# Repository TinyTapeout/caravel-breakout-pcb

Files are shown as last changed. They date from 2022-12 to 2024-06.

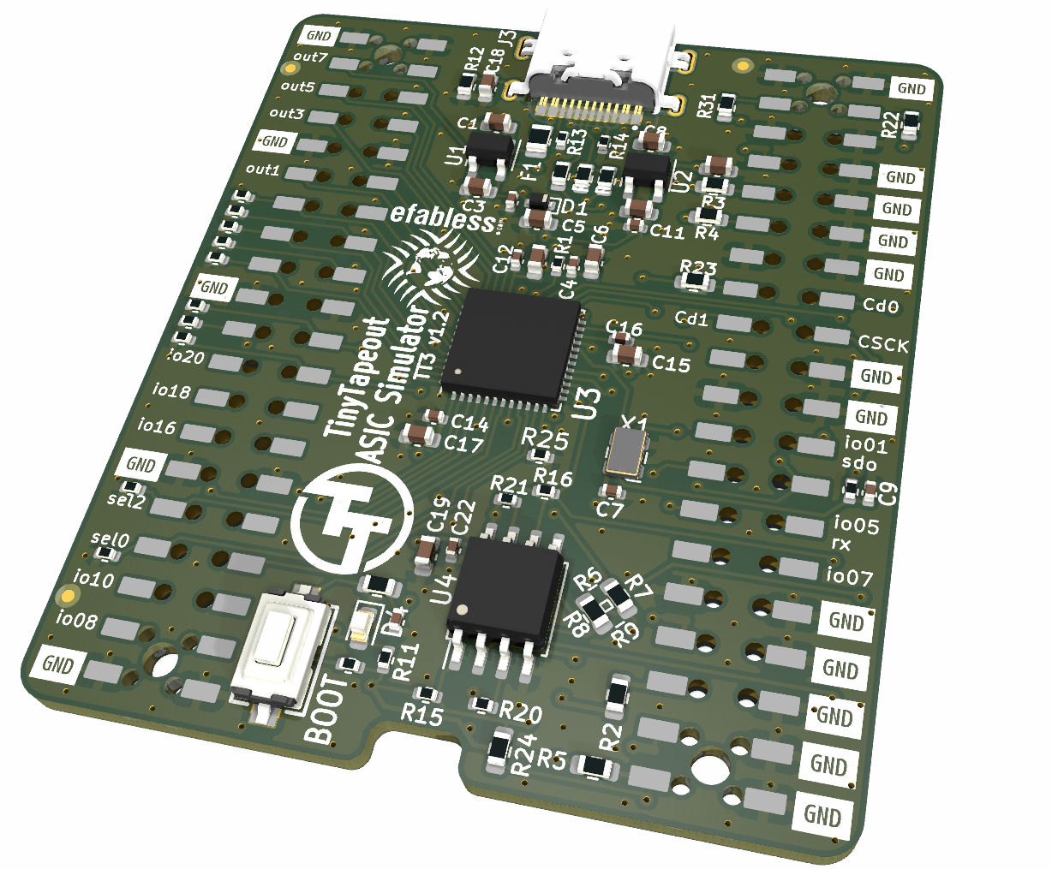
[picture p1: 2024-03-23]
ASIC-simulator/breakout-fpga-ICE40UP5K-TT3/doc/ice40up5kbkout-pcb.png

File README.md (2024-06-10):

# caravel-breakout-pcb - deprecated

> [!WARNING]
> This repo is deprecated. Use [TinyTapeout/breakout-pcb](https://github.com/tinytapeout/breakout-pcb) instead.

A set of breakouts/carrier boards for the Caravel ASIC used in eFabless MPW runs and a little FPGA adapter for simulating the TinyTapeout design, to be used alongside the [Tiny Tapeout 4+ Demo Board](https://github.com/TinyTapeout/tt-demo-pcb), the [Tiny Tapeout 1-3 Demo Board](https://github.com/TinyTapeout/tt123-demo-pcb), and/or other custom designs.

The ASIC board designs are based on the original breakout [published here](https://github.com/efabless/caravel_board/tree/main/hardware/breakout), optimised for single-sided surface mount assembly and ease of integration into other projects.

Design files are in KiCad 6 format, custom library parts can be found in [this external repo](https://github.com/omerk/ok-kicad-libs).

# PCBs sponsored by Aisler!

Thanks [Aisler](https://aisler.net/) for sponsoring our PCB development.

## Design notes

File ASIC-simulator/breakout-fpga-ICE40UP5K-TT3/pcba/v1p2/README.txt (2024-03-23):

TT3-compatible FPGA ASIC simulator 
(C) 2023,2024 Pat Deegan

This directory contains everything required for PCBA.

Gerbers in gerber/

B.O.M. to use in bom/BOM.csv

PnP placement file in placement/

Schematic and more info up one level, in doc/

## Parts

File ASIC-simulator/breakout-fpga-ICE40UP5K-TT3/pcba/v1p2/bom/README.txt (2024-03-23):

BOM stuffed depends on desired variant: see schematic.

However, for current PCBA we want to use something that can be used stand-alone, won't impact/require the demoboard flash (standalone variant).

Simplified and reviewed in 

   BOM.csv

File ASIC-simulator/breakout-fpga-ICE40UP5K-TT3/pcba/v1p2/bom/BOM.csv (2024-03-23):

Item | Qty | Reference | DNP | Value | Characteristics | MPN | MPN_ALT | DigikeyPN | Footprint | Datasheet | Display Value | Variant
Source: | caravel-breakout-fpga-ICE40UP5K-TT3.kicad_sch
Date: | Thu 11 Jan 2024 09:32:29 PM
Tool: | Eeschema 7.0.10-7.0.10~ubuntu22.04.1
Generator: | /usr/share/kicad/plugins/bom_csv_grouped_by_val_wDNP.py
Variants included: | {'PROG_CRAM': False, 'DEMOBOARD_DEPENDENT': False}
Component Count: | 72
Collated Components:
Item | Qty | Reference | DNP | Value | Characteristics | MPN | MPN_ALT | DigikeyPN | Footprint | Datasheet | Display Value
1 | 9 | C1,C3,C5,C6,C8,C10,C13,C15,C17 | 0 | 4.7u | 4.7u 0603 | CL10A475KP8NNNC | GRT188R61C475KE13J | 1276-1044-1-ND | Capacitor_SMD:C_0603_1608Metric
2 | 10 | C2,C4,C7,C9,C11,C12,C14,C16,C21,C22 | 0 | 0.1u | 0.1u 0402 | CL05A104KA5NNNC |  | 1276-1043-1-ND | Capacitor_SMD:C_0402_1005Metric
5 | 2 | CON1,CON2 | 0 | REF-182665-01 | 40 pos 100mil bottom + top | M20-7812045 | FH-00339 | 952-3218-ND | BreakoutCommon:FH-00339 | ~
6 | 1 | D1 | 0 | 1N4148WT-7 |  | 1N4148WT-7 | 1N4148XHE3-TP | 1N4148WTDICT-ND | Diode_SMD:D_SOD-523
8 | 1 | F1 | 0 | 350mA | Polyfuse 350mA Hold 0805 | 0ZCK0035FF2G |  | 507-1812-1-ND | Fuse:Fuse_0805_2012Metric | ~
9 | 1 | J3 | 0 | USB4500-03-0-A_REVA | USB 2 Recept 16+8 Dummy | USB4500-03-0-A |  | 2073-USB4500-03-0-ACT-ND | TinyTapeout:GCT_USB4500-03-0-A_REVA
10 | 1 | R1 | 0 | R_100R_0402 | 100R 1% 0402 | RC0402FR-07100RL |  | 311-100LRCT-ND | Resistor_SMD:R_0402_1005Metric | ~ | 100R
11 | 4 | R4,R5,R22,R24 | DNPs: 4 (final qty: 4) | 0R | 0R JUMPER 0603 | CRG0603ZR |  | A106051CT-ND | Resistor_SMD:R_0603_1608Metric | ~ | 0R
12 | 2 | R7,R8 | DNPs: 2 (final qty: 2) | 0R | 0R JUMPER 0603 | CRG0603ZR |  | A106051CT-ND | Resistor_SMD:R_0603_1608Metric |  | 0R
13 | 9 | R10,R15,R16,R20,R21,R25,R26,R28,R30 | 0 | R_10k_0402 | 10k 0402 | RC0402FR-0710KL |  | 311-10.0KLRCT-ND | Resistor_SMD:R_0402_1005Metric | ~ | 10k
16 | 2 | R13,R14 | 0 | 5.1k | 5.1k 0402 1% | AC0402FR-135K1L |  | 13-AC0402FR-135K1LCT-ND | Resistor_SMD:R_0402_1005Metric | ~
17 | 2 | R17,R29 | 0 | 1k5 | 1.5k 0603 1% | CR0603-FX-1501ELF | WR06X1501FTL | 118-CR0603-FX-1501ELFCT-ND | Resistor_SMD:R_0603_1608Metric | ~ | 1k5
18 | 2 | R18,R19 | 0 | 68R | 68R 0603 | CR0603-FX-68R0ELF | WR06X68R0FTL | CR0603-FX-68R0ELF | Resistor_SMD:R_0603_1608Metric | ~ | 68R
19 | 8 | R27,R32,R33,R34,R35,R36,R37,R38 | 0 | R_100k_0402 | 100k 0402 | RC0402FR-07100KL | WR04X1003FTL | 311-100KLRCT-ND | Resistor_SMD:R_0402_1005Metric | ~ | 100k
20 | 1 | SW1 | 0 | 434121025816 | NO MOM tactile switch | 434121025816 | TS10-63-26-BE-250-SMT-TR |  | TinyTapeout:434121025816 | ~
21 | 1 | U1 | 0 | AP2112K-3.3 |  | AP2112K-3.3TRG1 |  | AP2112K-3.3TRG1DICT-ND | Package_TO_SOT_SMD:SOT-23-5 | https://www.diodes.com/assets/Datasheets/AP2112.pdf
22 | 1 | U2 | 0 | AP2112K-1.2 |  | AP2112K-1.2TRG1 |  | 31-AP2112K-1.2TRG1CT-ND | Package_TO_SOT_SMD:SOT-23-5 | https://www.diodes.com/assets/Datasheets/AP2112.pdf
23 | 1 | U3 | 0 | ICE40UP5K-SG48ITR |  | ICE40UP5K-SG48I |  | 220-2212-1-ND | Package_DFN_QFN:QFN-48-1EP_7x7mm_P0.5mm_EP5.6x5.6mm
24 | 1 | U4 | 0 | W25Q32JVSSIM |  | W25Q32JVSSIQ |  | W25Q32JVSSIQ-ND | Package_SO:SOIC-8_5.23x5.23mm_P1.27mm
25 | 1 | X1 | 0 | 20MHz |  | 830208220401 |  | 1923-830208220401CT-ND | Oscillator:Oscillator_SMD_ECS_2520MV-xxx-xx-4Pin_2.5x2.0mm | https://www.ecsxtal.com/store/pdf/ECS-2520MV.pdf
Individual Components:
Item | Qty | Reference | DNP | Value | Characteristics | MPN | MPN_ALT | DigikeyPN | Footprint | Datasheet | Display Value | Variant
 |  | C1 |  | 4.7u | 4.7u 0603 | CL10A475KP8NNNC | GRT188R61C475KE13J | 1276-1044-1-ND | Capacitor_SMD:C_0603_1608Metric |  |  | USE_STANDALONE
 |  | C2 |  | 0.1u | 0.1u 0402 | CL05A104KA5NNNC |  | 1276-1043-1-ND | Capacitor_SMD:C_0402_1005Metric
 |  | C3 |  | 4.7u | 4.7u 0603 | CL10A475KP8NNNC | GRT188R61C475KE13J | 1276-1044-1-ND | Capacitor_SMD:C_0603_1608Metric |  |  | USE_STANDALONE
 |  | C4 |  | 0.1u | 0.1u 0402 | CL05A104KA5NNNC |  | 1276-1043-1-ND | Capacitor_SMD:C_0402_1005Metric
 |  | C5 |  | 4.7u | 4.7u 0603 | CL10A475KP8NNNC | GRT188R61C475KE13J | 1276-1044-1-ND | Capacitor_SMD:C_0603_1608Metric
 |  | C6 |  | 4.7u | 4.7u 0603 | CL10A475KP8NNNC | GRT188R61C475KE13J | 1276-1044-1-ND | Capacitor_SMD:C_0603_1608Metric
 |  | C7 |  | 0.1u | 0.1u 0402 | CL05A104KA5NNNC |  | 1276-1043-1-ND | Capacitor_SMD:C_0402_1005Metric
 |  | C8 |  | 4.7u | 4.7u 0603 | CL10A475KP8NNNC | GRT188R61C475KE13J | 1276-1044-1-ND | Capacitor_SMD:C_0603_1608Metric
 |  | C9 |  | 0.1u | 0.1u 0402 | CL05A104KA5NNNC |  | 1276-1043-1-ND | Capacitor_SMD:C_0402_1005Metric
 |  | C10 |  | 4.7u | 4.7u 0603 | CL10A475KP8NNNC | GRT188R61C475KE13J | 1276-1044-1-ND | Capacitor_SMD:C_0603_1608Metric
 |  | C11 |  | 0.1u | 0.1u 0402 | CL05A104KA5NNNC |  | 1276-1043-1-ND | Capacitor_SMD:C_0402_1005Metric
 |  | C12 |  | 0.1u | 0.1u 0402 | CL05A104KA5NNNC |  | 1276-1043-1-ND | Capacitor_SMD:C_0402_1005Metric
 |  | C13 |  | 4.7u | 4.7u 0603 | CL10A475KP8NNNC | GRT188R61C475KE13J | 1276-1044-1-ND | Capacitor_SMD:C_0603_1608Metric
 |  | C14 |  | 0.1u | 0.1u 0402 | CL05A104KA5NNNC |  | 1276-1043-1-ND | Capacitor_SMD:C_0402_1005Metric
 |  | C15 |  | 4.7u | 4.7u 0603 | CL10A475KP8NNNC | GRT188R61C475KE13J | 1276-1044-1-ND | Capacitor_SMD:C_0603_1608Metric
 |  | C16 |  | 0.1u | 0.1u 0402 | CL05A104KA5NNNC |  | 1276-1043-1-ND | Capacitor_SMD:C_0402_1005Metric
 |  | C17 |  | 4.7u | 4.7u 0603 | CL10A475KP8NNNC | GRT188R61C475KE13J | 1276-1044-1-ND | Capacitor_SMD:C_0603_1608Metric
 |  | C18 | DNP | 6800pF | 6800p 0603 |  |  |  | Capacitor_SMD:C_0603_1608Metric | ~ |  | USB
 |  | C19 | DNP | DNI |  |  |  |  | Capacitor_SMD:C_0603_1608Metric
 |  | C20 | DNP | DNI |  |  |  |  | Capacitor_SMD:C_0603_1608Metric
 |  | C21 |  | 0.1u | 0.1u 0402 | CL05A104KA5NNNC |  | 1276-1043-1-ND | Capacitor_SMD:C_0402_1005Metric
 |  | C22 |  | 0.1u | 0.1u 0402 | CL05A104KA5NNNC |  | 1276-1043-1-ND | Capacitor_SMD:C_0402_1005Metric
 |  | CON1 |  | REF-182665-01 | 40 pos 100mil bottom + top | M20-7812045 | FH-00339 | 952-3218-ND | BreakoutCommon:FH-00339 | ~
 |  | CON2 |  | REF-182665-01 | 40 pos 100mil bottom + top | M20-7812045 | FH-00339 | 952-3218-ND | BreakoutCommon:FH-00339 | ~
 |  | D1 |  | 1N4148WT-7 |  | 1N4148WT-7 | 1N4148XHE3-TP | 1N4148WTDICT-ND | Diode_SMD:D_SOD-523
 |  | D4 | DNP | LED |  |  |  |  | LED_SMD:LED_0603_1608Metric | ~
 |  | F1 |  | 350mA | Polyfuse 350mA Hold 0805 | 0ZCK0035FF2G |  | 507-1812-1-ND | Fuse:Fuse_0805_2012Metric | ~ |  | USB
 |  | J3 |  | USB4500-03-0-A_REVA | USB 2 Recept 16+8 Dummy | USB4500-03-0-A |  | 2073-USB4500-03-0-ACT-ND | TinyTapeout:GCT_USB4500-03-0-A_REVA
 |  | R1 |  | R_100R_0402 | 100R 1% 0402 | RC0402FR-07100RL |  | 311-100LRCT-ND | Resistor_SMD:R_0402_1005Metric | ~ | 100R
 |  | R2 | DNP | 0R | 0R JUMPER 0603 | CRG0603ZR |  | A106051CT-ND | Resistor_SMD:R_0603_1608Metric | ~ | 0R | DEMOBOARD_DEPENDENT
 |  | R3 | DNP | 0R | 0R JUMPER 0603 | CRG0603ZR |  | A106051CT-ND | Resistor_SMD:R_0603_1608Metric | ~ | 0R | DEMOBOARD_DEPENDENT
 |  | R4 |  | 0R | 0R JUMPER 0603 | CRG0603ZR |  | A106051CT-ND | Resistor_SMD:R_0603_1608Metric | ~ | 0R | DEMOBOARD_BACKPOWERED
 |  | R5 |  | 0R | 0R JUMPER 0603 | CRG0603ZR |  | A106051CT-ND | Resistor_SMD:R_0603_1608Metric | ~ | 0R | DEMOBOARD_BACKPOWERED
 |  | R6 | DNP | 0R | 0R JUMPER 0603 | CRG0603ZR |  | A106051CT-ND | Resistor_SMD:R_0603_1608Metric |  | 0R | PROG_CRAM
 |  | R7 |  | 0R | 0R JUMPER 0603 | CRG0603ZR |  | A106051CT-ND | Resistor_SMD:R_0603_1608Metric |  | 0R | PROG_FLASH
 |  | R8 |  | 0R | 0R JUMPER 0603 | CRG0603ZR |  | A106051CT-ND | Resistor_SMD:R_0603_1608Metric |  | 0R | PROG_FLASH
 |  | R9 | DNP | 0R | 0R JUMPER 0603 | CRG0603ZR |  | A106051CT-ND | Resistor_SMD:R_0603_1608Metric |  | 0R | PROG_CRAM
 |  | R10 |  | R_10k_0402 | 10k 0402 | RC0402FR-0710KL |  | 311-10.0KLRCT-ND | Resistor_SMD:R_0402_1005Metric | ~ | 10k
 |  | R11 | DNP | R_2k_0402 | 2k 0402 | RC0402FR-072KL |  | 311-2KLRCT-ND | Resistor_SMD:R_0402_1005Metric | ~ | 2k
 |  | R12 | DNP | 1M | 1M 0603 |  |  |  | Resistor_SMD:R_0603_1608Metric | ~ |  | USB
 |  | R13 |  | 5.1k | 5.1k 0402 1% | AC0402FR-135K1L |  | 13-AC0402FR-135K1LCT-ND | Resistor_SMD:R_0402_1005Metric | ~ |  | USB
 |  | R14 |  | 5.1k | 5.1k 0402 1% | AC0402FR-135K1L |  | 13-AC0402FR-135K1LCT-ND | Resistor_SMD:R_0402_1005Metric | ~ |  | USB
 |  | R15 |  | R_10k_0402 | 10k 0402 | RC0402FR-0710KL |  | 311-10.0KLRCT-ND | Resistor_SMD:R_0402_1005Metric | ~ | 10k
 |  | R16 |  | R_10k_0402 | 10k 0402 | RC0402FR-0710KL |  | 311-10.0KLRCT-ND | Resistor_SMD:R_0402_1005Metric | ~ | 10k
 |  | R17 |  | 1k5 | 1.5k 0603 1% | CR0603-FX-1501ELF | WR06X1501FTL | 118-CR0603-FX-1501ELFCT-ND | Resistor_SMD:R_0603_1608Metric | ~ | 1k5 | USB_COMM
 |  | R18 |  | 68R | 68R 0603 | CR0603-FX-68R0ELF | WR06X68R0FTL | CR0603-FX-68R0ELF | Resistor_SMD:R_0603_1608Metric | ~ | 68R | USB_COMM
 |  | R19 |  | 68R | 68R 0603 | CR0603-FX-68R0ELF | WR06X68R0FTL | CR0603-FX-68R0ELF | Resistor_SMD:R_0603_1608Metric | ~ | 68R | USB_COMM
 |  | R20 |  | R_10k_0402 | 10k 0402 | RC0402FR-0710KL |  | 311-10.0KLRCT-ND | Resistor_SMD:R_0402_1005Metric | ~ | 10k
 |  | R21 |  | R_10k_0402 | 10k 0402 | RC0402FR-0710KL |  | 311-10.0KLRCT-ND | Resistor_SMD:R_0402_1005Metric | ~ | 10k
 |  | R22 |  | 0R | 0R JUMPER 0603 | CRG0603ZR |  | A106051CT-ND | Resistor_SMD:R_0603_1608Metric | ~ | 0R
 |  | R23 | DNP | 0R | 0R JUMPER 0603 | CRG0603ZR |  | A106051CT-ND | Resistor_SMD:R_0603_1608Metric | ~ | 0R | DEMOBOARD_DEPENDENT
 |  | R24 |  | 0R | 0R JUMPER 0603 | CRG0603ZR |  | A106051CT-ND | Resistor_SMD:R_0603_1608Metric | ~ | 0R | USE_STANDALONE
 |  | R25 |  | R_10k_0402 | 10k 0402 | RC0402FR-0710KL |  | 311-10.0KLRCT-ND | Resistor_SMD:R_0402_1005Metric | ~ | 10k
 |  | R26 |  | R_10k_0402 | 10k 0402 | RC0402FR-0710KL |  | 311-10.0KLRCT-ND | Resistor_SMD:R_0402_1005Metric | ~ | 10k
 |  | R27 |  | R_100k_0402 | 100k 0402 | RC0402FR-07100KL | WR04X1003FTL | 311-100KLRCT-ND | Resistor_SMD:R_0402_1005Metric | ~ | 100k
 |  | R28 |  | R_10k_0402 | 10k 0402 | RC0402FR-0710KL |  | 311-10.0KLRCT-ND | Resistor_SMD:R_0402_1005Metric | ~ | 10k
 |  | R29 |  | 1k5 | 1.5k 0603 1% | CR0603-FX-1501ELF | WR06X1501FTL | 118-CR0603-FX-1501ELFCT-ND | Resistor_SMD:R_0603_1608Metric | ~ | 1k5
 |  | R30 |  | R_10k_0402 | 10k 0402 | RC0402FR-0710KL |  | 311-10.0KLRCT-ND | Resistor_SMD:R_0402_1005Metric | ~ | 10k
 |  | R31 | DNP | 0R | 0R JUMPER 0603 | CRG0603ZR |  | A106051CT-ND | Resistor_SMD:R_0603_1608Metric | ~ | 0R | DEMOBOARD_DEPENDENT
 |  | R32 |  | R_100k_0402 | 100k 0402 | RC0402FR-07100KL | WR04X1003FTL | 311-100KLRCT-ND | Resistor_SMD:R_0402_1005Metric | ~ | 100k
 |  | R33 |  | R_100k_0402 | 100k 0402 | RC0402FR-07100KL | WR04X1003FTL | 311-100KLRCT-ND | Resistor_SMD:R_0402_1005Metric | ~ | 100k
 |  | R34 |  | R_100k_0402 | 100k 0402 | RC0402FR-07100KL | WR04X1003FTL | 311-100KLRCT-ND | Resistor_SMD:R_0402_1005Metric | ~ | 100k
 |  | R35 |  | R_100k_0402 | 100k 0402 | RC0402FR-07100KL | WR04X1003FTL | 311-100KLRCT-ND | Resistor_SMD:R_0402_1005Metric | ~ | 100k
 |  | R36 |  | R_100k_0402 | 100k 0402 | RC0402FR-07100KL | WR04X1003FTL | 311-100KLRCT-ND | Resistor_SMD:R_0402_1005Metric | ~ | 100k
 |  | R37 |  | R_100k_0402 | 100k 0402 | RC0402FR-07100KL | WR04X1003FTL | 311-100KLRCT-ND | Resistor_SMD:R_0402_1005Metric | ~ | 100k
 |  | R38 |  | R_100k_0402 | 100k 0402 | RC0402FR-07100KL | WR04X1003FTL | 311-100KLRCT-ND | Resistor_SMD:R_0402_1005Metric | ~ | 100k
 |  | SW1 |  | 434121025816 | NO MOM tactile switch | 434121025816 | TS10-63-26-BE-250-SMT-TR |  | TinyTapeout:434121025816 | ~
 |  | U1 |  | AP2112K-3.3 |  | AP2112K-3.3TRG1 |  | AP2112K-3.3TRG1DICT-ND | Package_TO_SOT_SMD:SOT-23-5 | https://www.diodes.com/assets/Datasheets/AP2112.pdf |  | USE_STANDALONE
 |  | U2 |  | AP2112K-1.2 |  | AP2112K-1.2TRG1 |  | 31-AP2112K-1.2TRG1CT-ND | Package_TO_SOT_SMD:SOT-23-5 | https://www.diodes.com/assets/Datasheets/AP2112.pdf
 |  | U3 |  | ICE40UP5K-SG48ITR |  | ICE40UP5K-SG48I |  | 220-2212-1-ND | Package_DFN_QFN:QFN-48-1EP_7x7mm_P0.5mm_EP5.6x5.6mm
 |  | U4 |  | W25Q32JVSSIM |  | W25Q32JVSSIQ |  | W25Q32JVSSIQ-ND | Package_SO:SOIC-8_5.23x5.23mm_P1.27mm |  |  | USE_STANDALONE
 |  | X1 |  | 20MHz |  | 830208220401 |  | 1923-830208220401CT-ND | Oscillator:Oscillator_SMD_ECS_2520MV-xxx-xx-4Pin_2.5x2.0mm | https://www.ecsxtal.com/store/pdf/ECS-2520MV.pdf |  | USE_STANDALONE

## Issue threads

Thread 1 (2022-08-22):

add easily probable ground power pads

mattvenn, 2022-08-22:
or use something like microbit. could put these on the motherboard too / instead

omerk, 2023-01-01:
With long headers poking through the "pass through", connectors probing individual signals should be fairly easy already but I'll see if we can add an easy-to-clip-to-scope-ground exposed ground pad like the TI devboards:

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

And ditto: it might not be a bad idea to have some easy to poke/clip test points on the demo board too. I'll add an issue on that repo.

omerk, 2023-03-20:
Closing this as we've moved this on to the main board.

Closed 2023-03-20.

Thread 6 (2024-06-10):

make pin1 marker for the black qfn breakout

mattvenn, 2024-06-10:
Proppy in the discord just soldered it the wrong way round.

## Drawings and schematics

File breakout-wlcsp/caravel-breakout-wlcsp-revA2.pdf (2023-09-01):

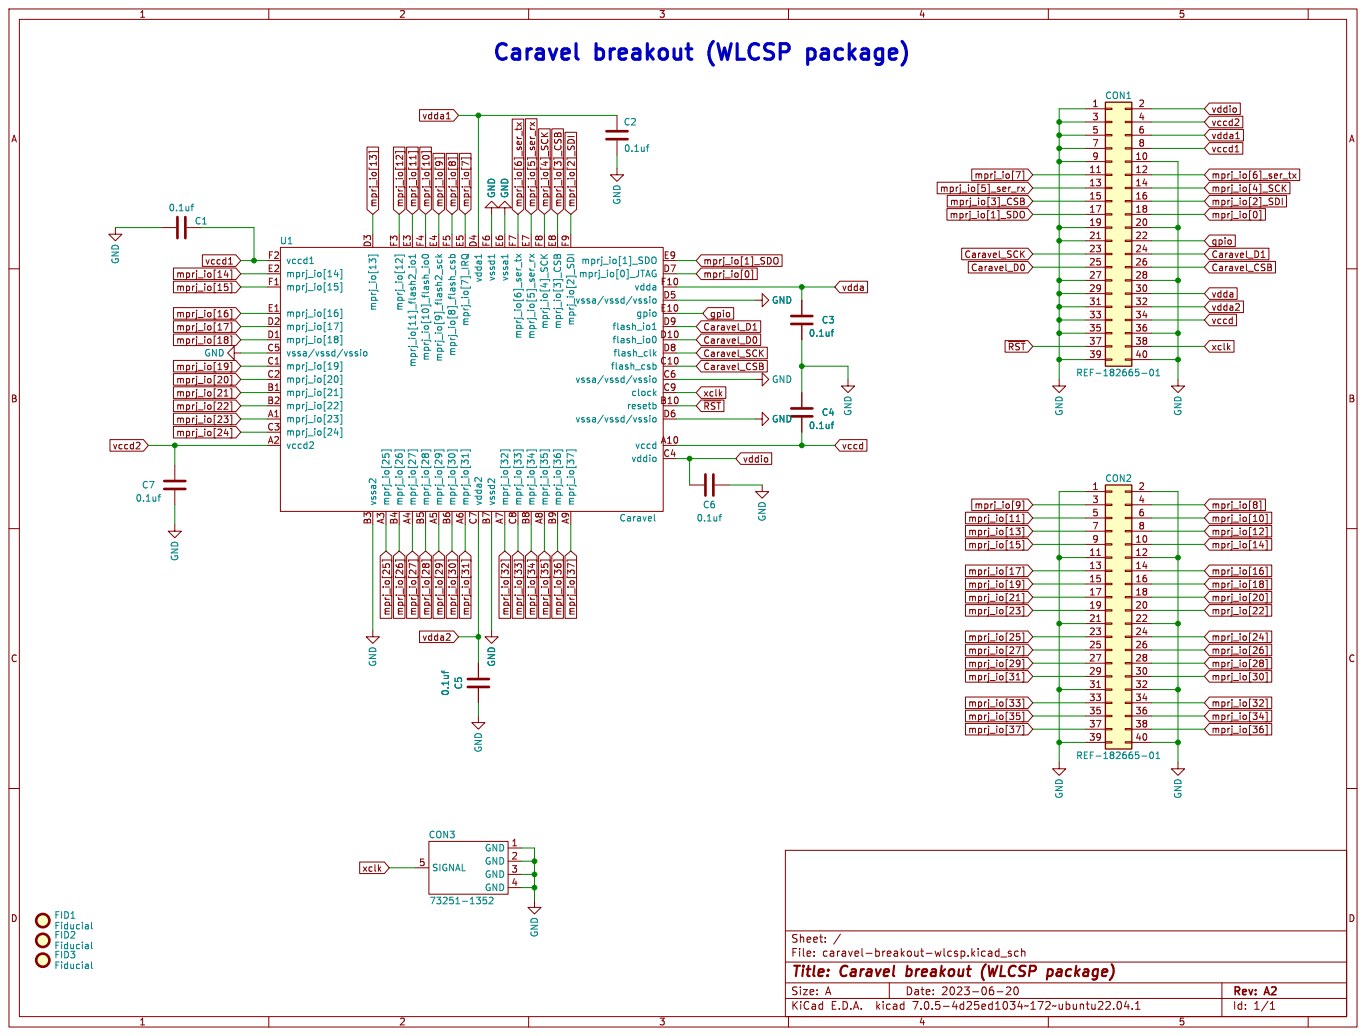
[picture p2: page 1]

Caravel breakout (WLCSP package)

Id: 1/1 Title: Caravel breakout (WLCSP package) File: caravel-breakout-wlcsp.kicad_sch Sheet: / mprj_io[23] A1

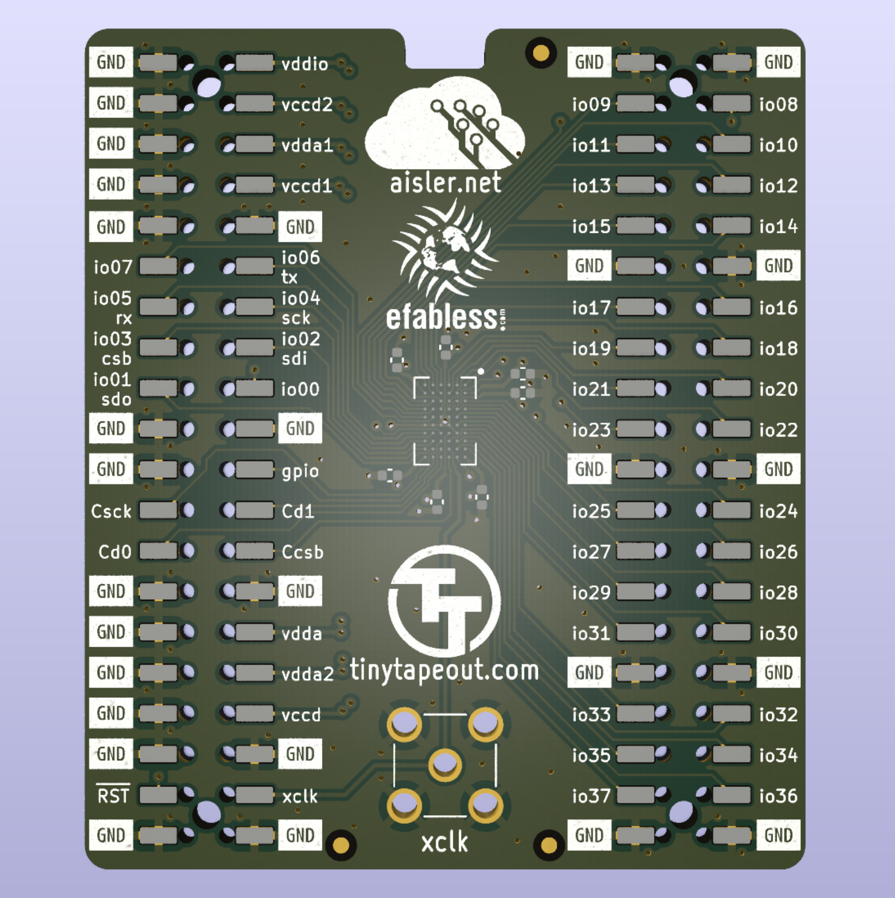
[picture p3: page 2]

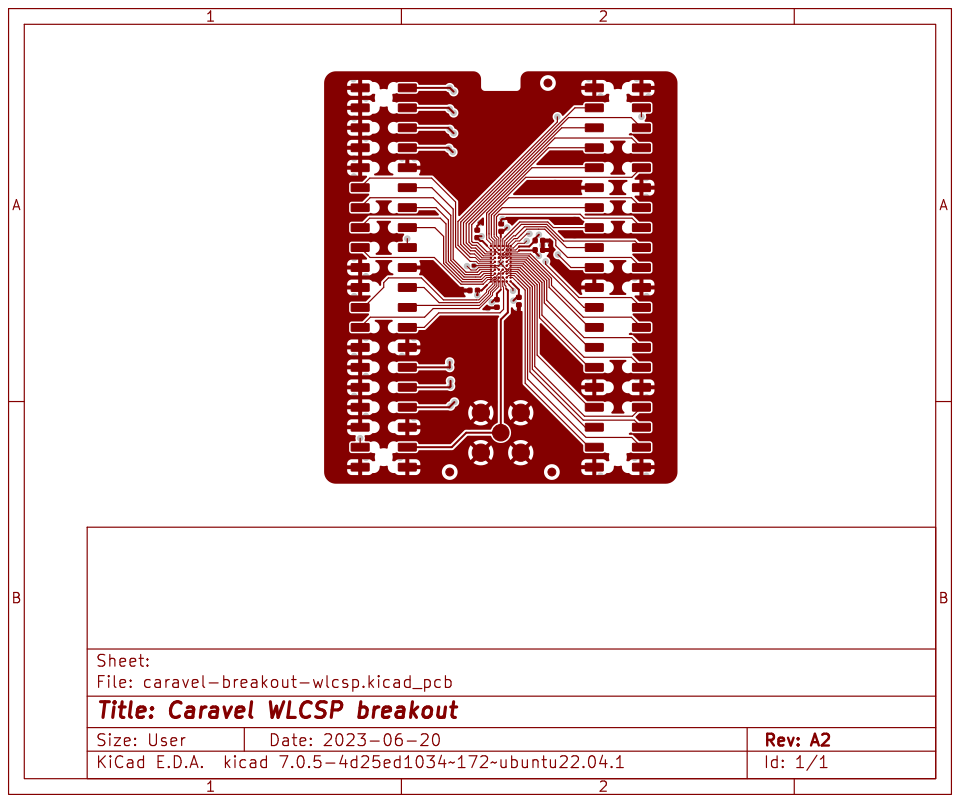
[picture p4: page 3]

Id: 1/1 Title: Caravel WLCSP breakout File: caravel-breakout-wlcsp.kicad_pcb Sheet:

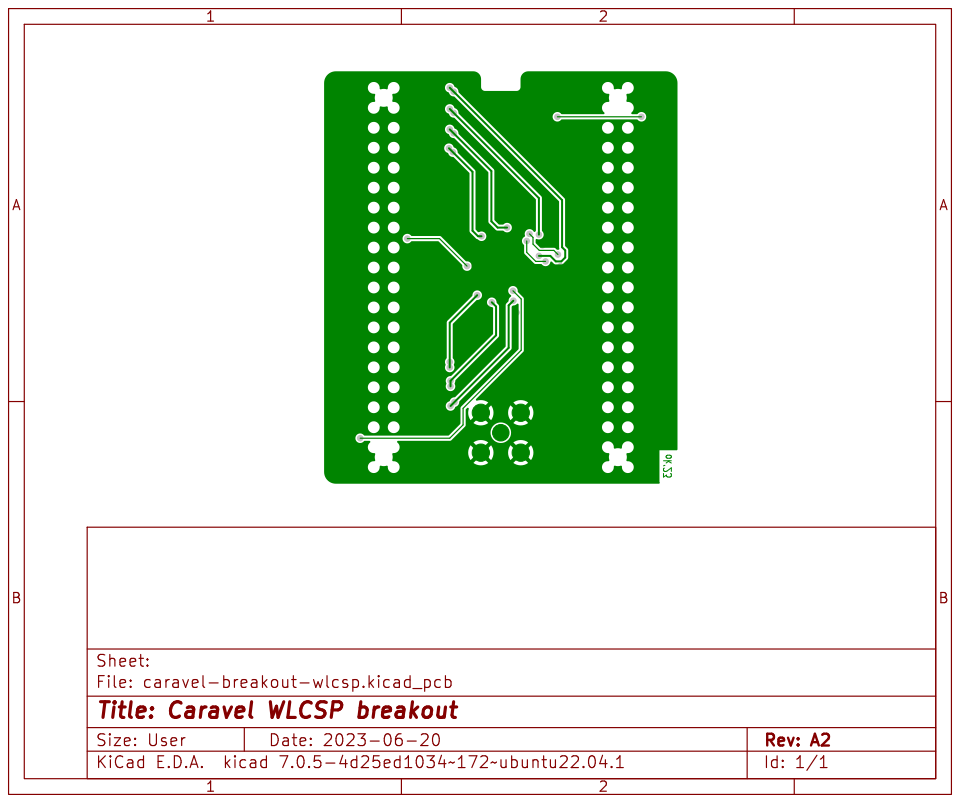
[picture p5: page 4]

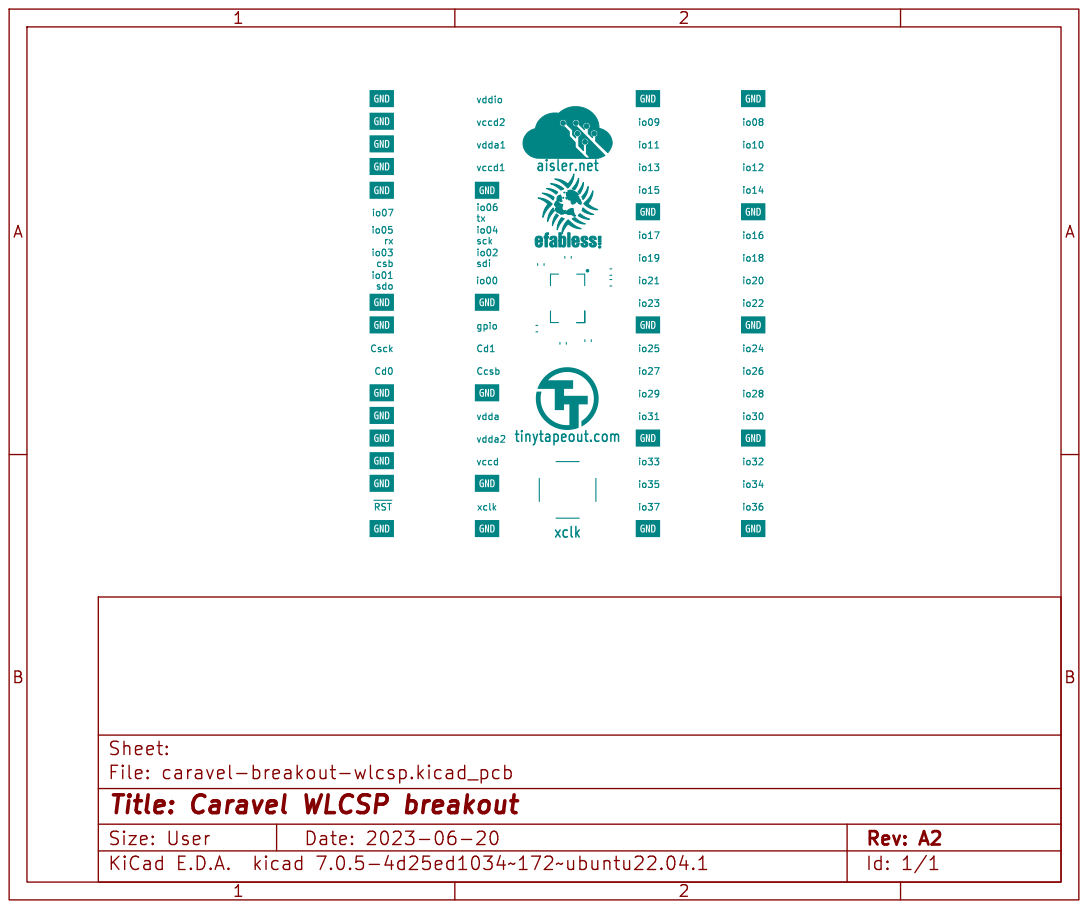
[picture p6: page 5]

Id: 1/1 Title: Caravel WLCSP breakout File: caravel-breakout-wlcsp.kicad_pcb Sheet:

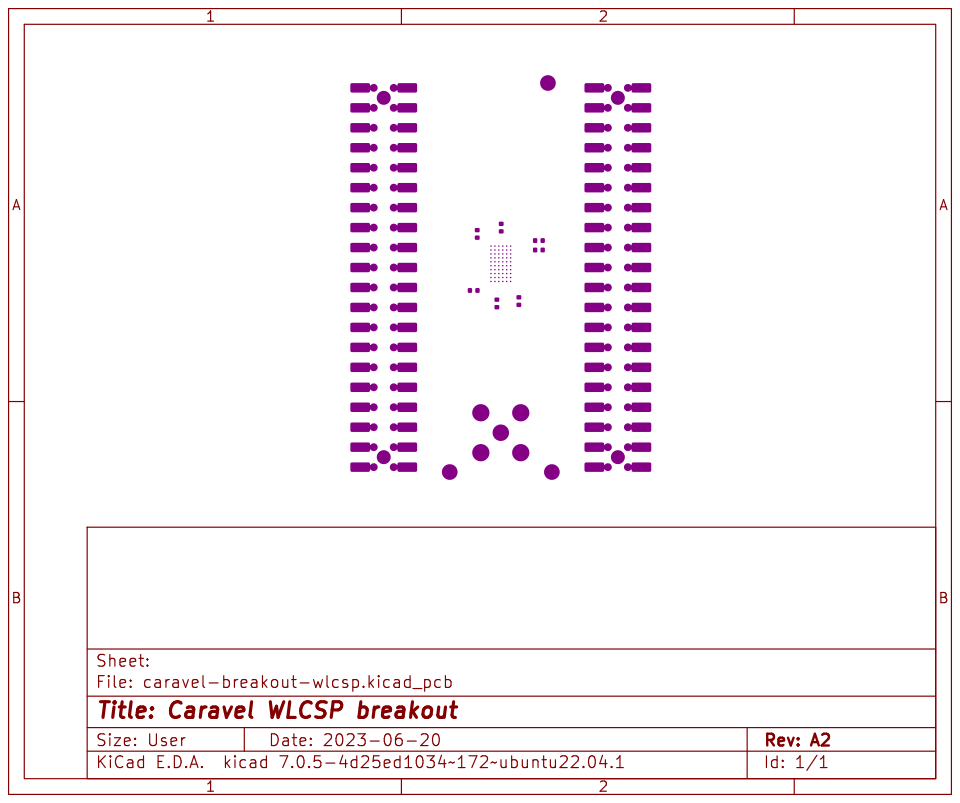
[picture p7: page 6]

Id: 1/1 Title: Caravel WLCSP breakout File: caravel-breakout-wlcsp.kicad_pcb Sheet:

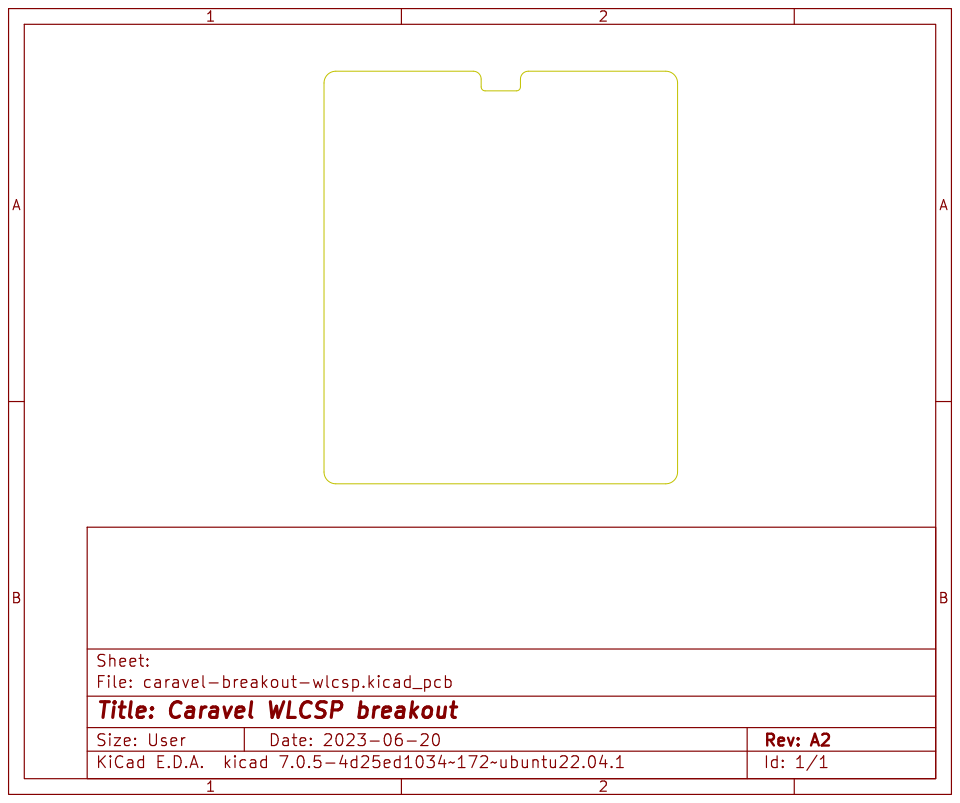
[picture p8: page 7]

Id: 1/1 Title: Caravel WLCSP breakout File: caravel-breakout-wlcsp.kicad_pcb Sheet:

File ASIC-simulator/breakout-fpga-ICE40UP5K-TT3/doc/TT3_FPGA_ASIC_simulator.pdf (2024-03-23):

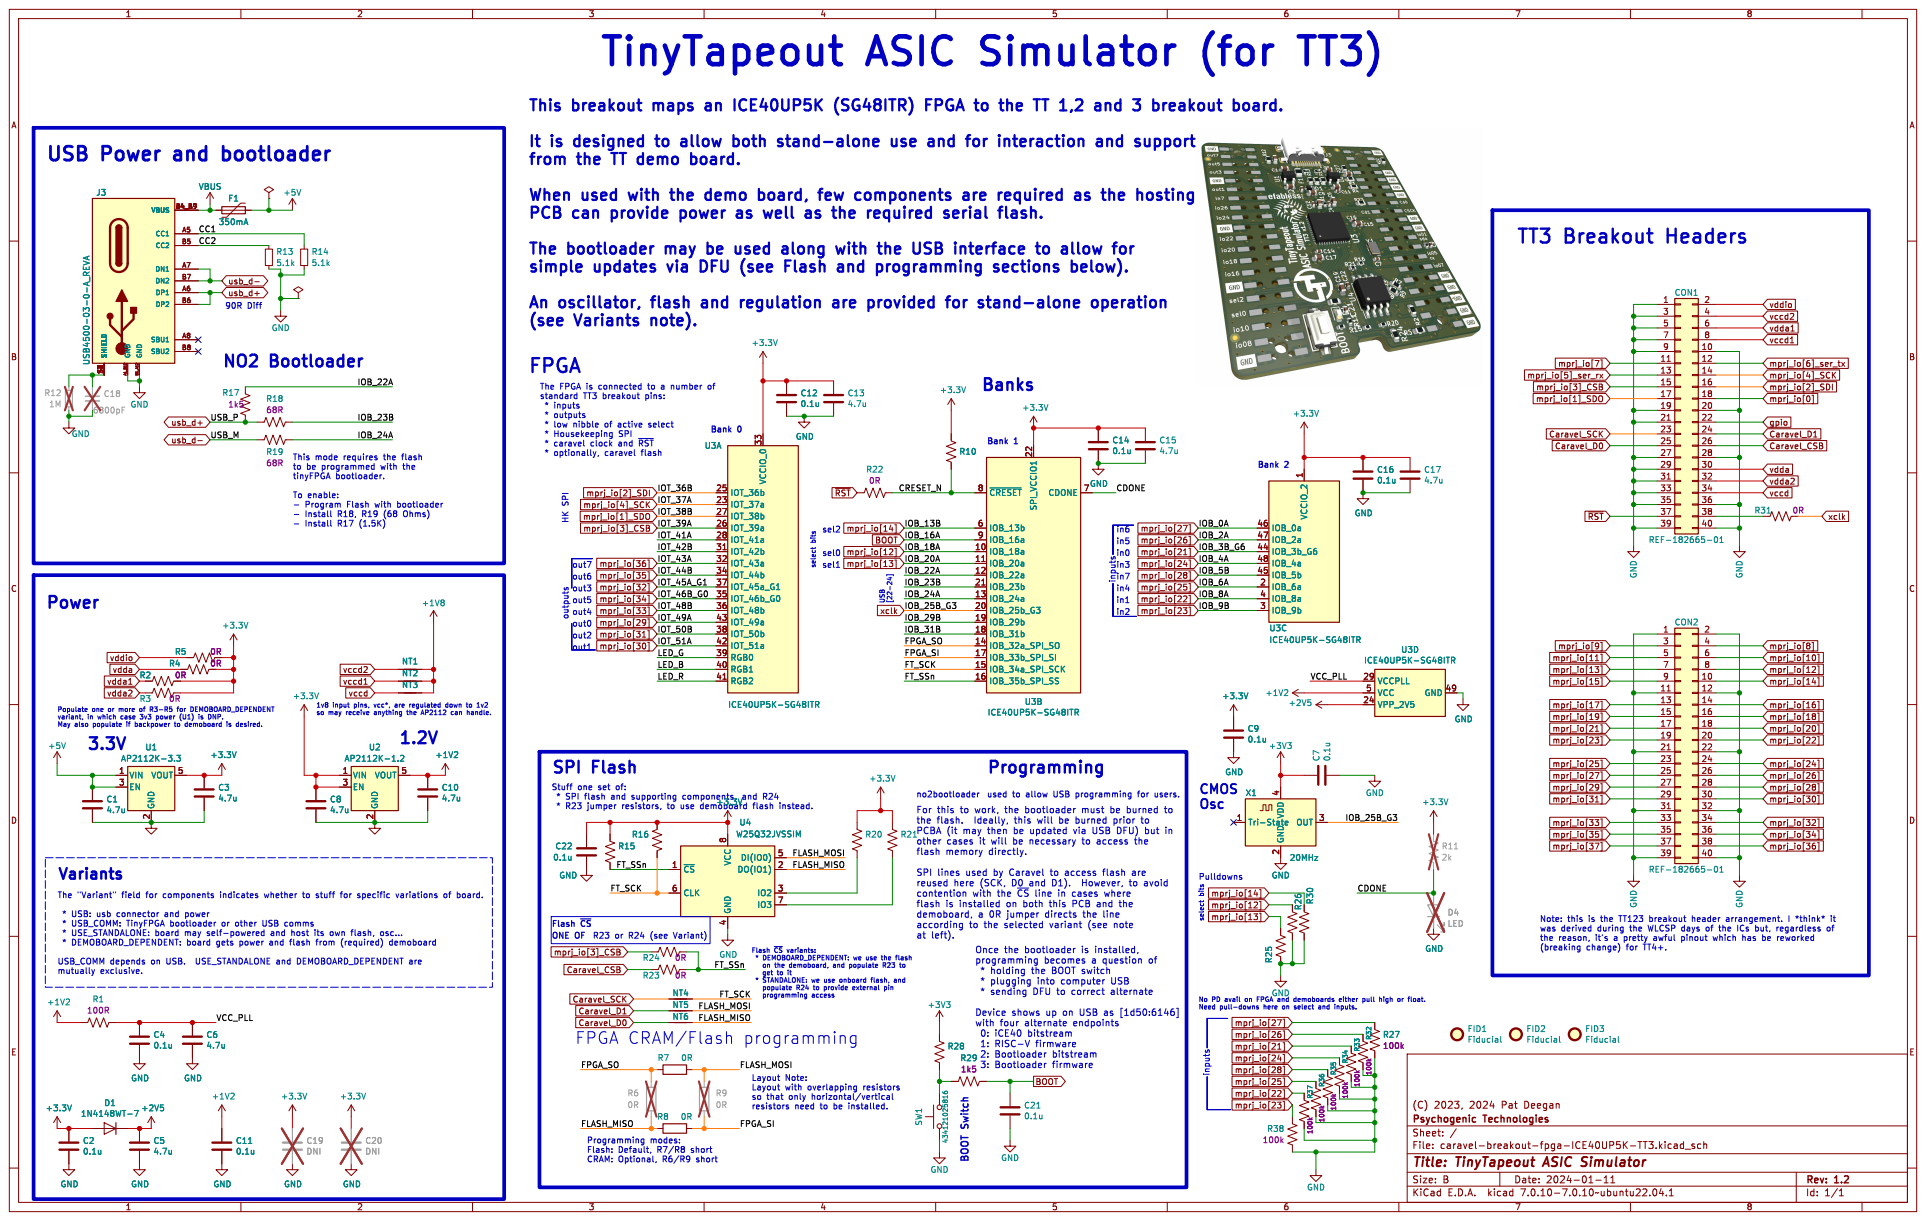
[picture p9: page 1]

out4 TinyTapeout ASIC Simulator (for TT3)

This breakout maps an ICE40UP5K (SG48ITR) FPGA to the TT 1,2 and 3 breakout board.

USB Power and bootloader

from the TT demo board.

When used with the demo board, few components are required as the hosting
PCB can provide power as well as the required serial flash.

The bootloader may be used along with the USB interface to allow for

This mode requires the flash
tinyFPGA bootloader. To enable: - Program Flash with bootloader

other cases it will be necessary to access the
flash memory directly. SPI lines used by Caravel to access flash are

the reason, it's a pretty awful pinout which has be reworked


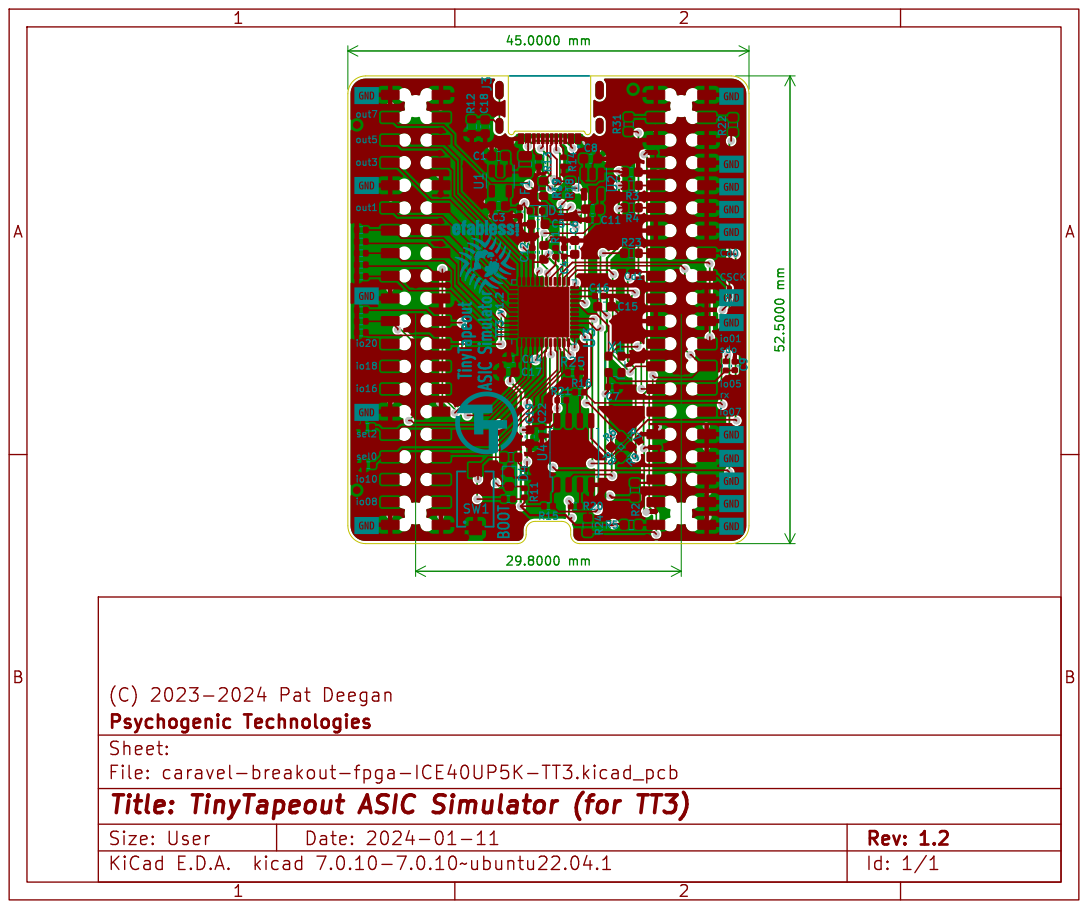
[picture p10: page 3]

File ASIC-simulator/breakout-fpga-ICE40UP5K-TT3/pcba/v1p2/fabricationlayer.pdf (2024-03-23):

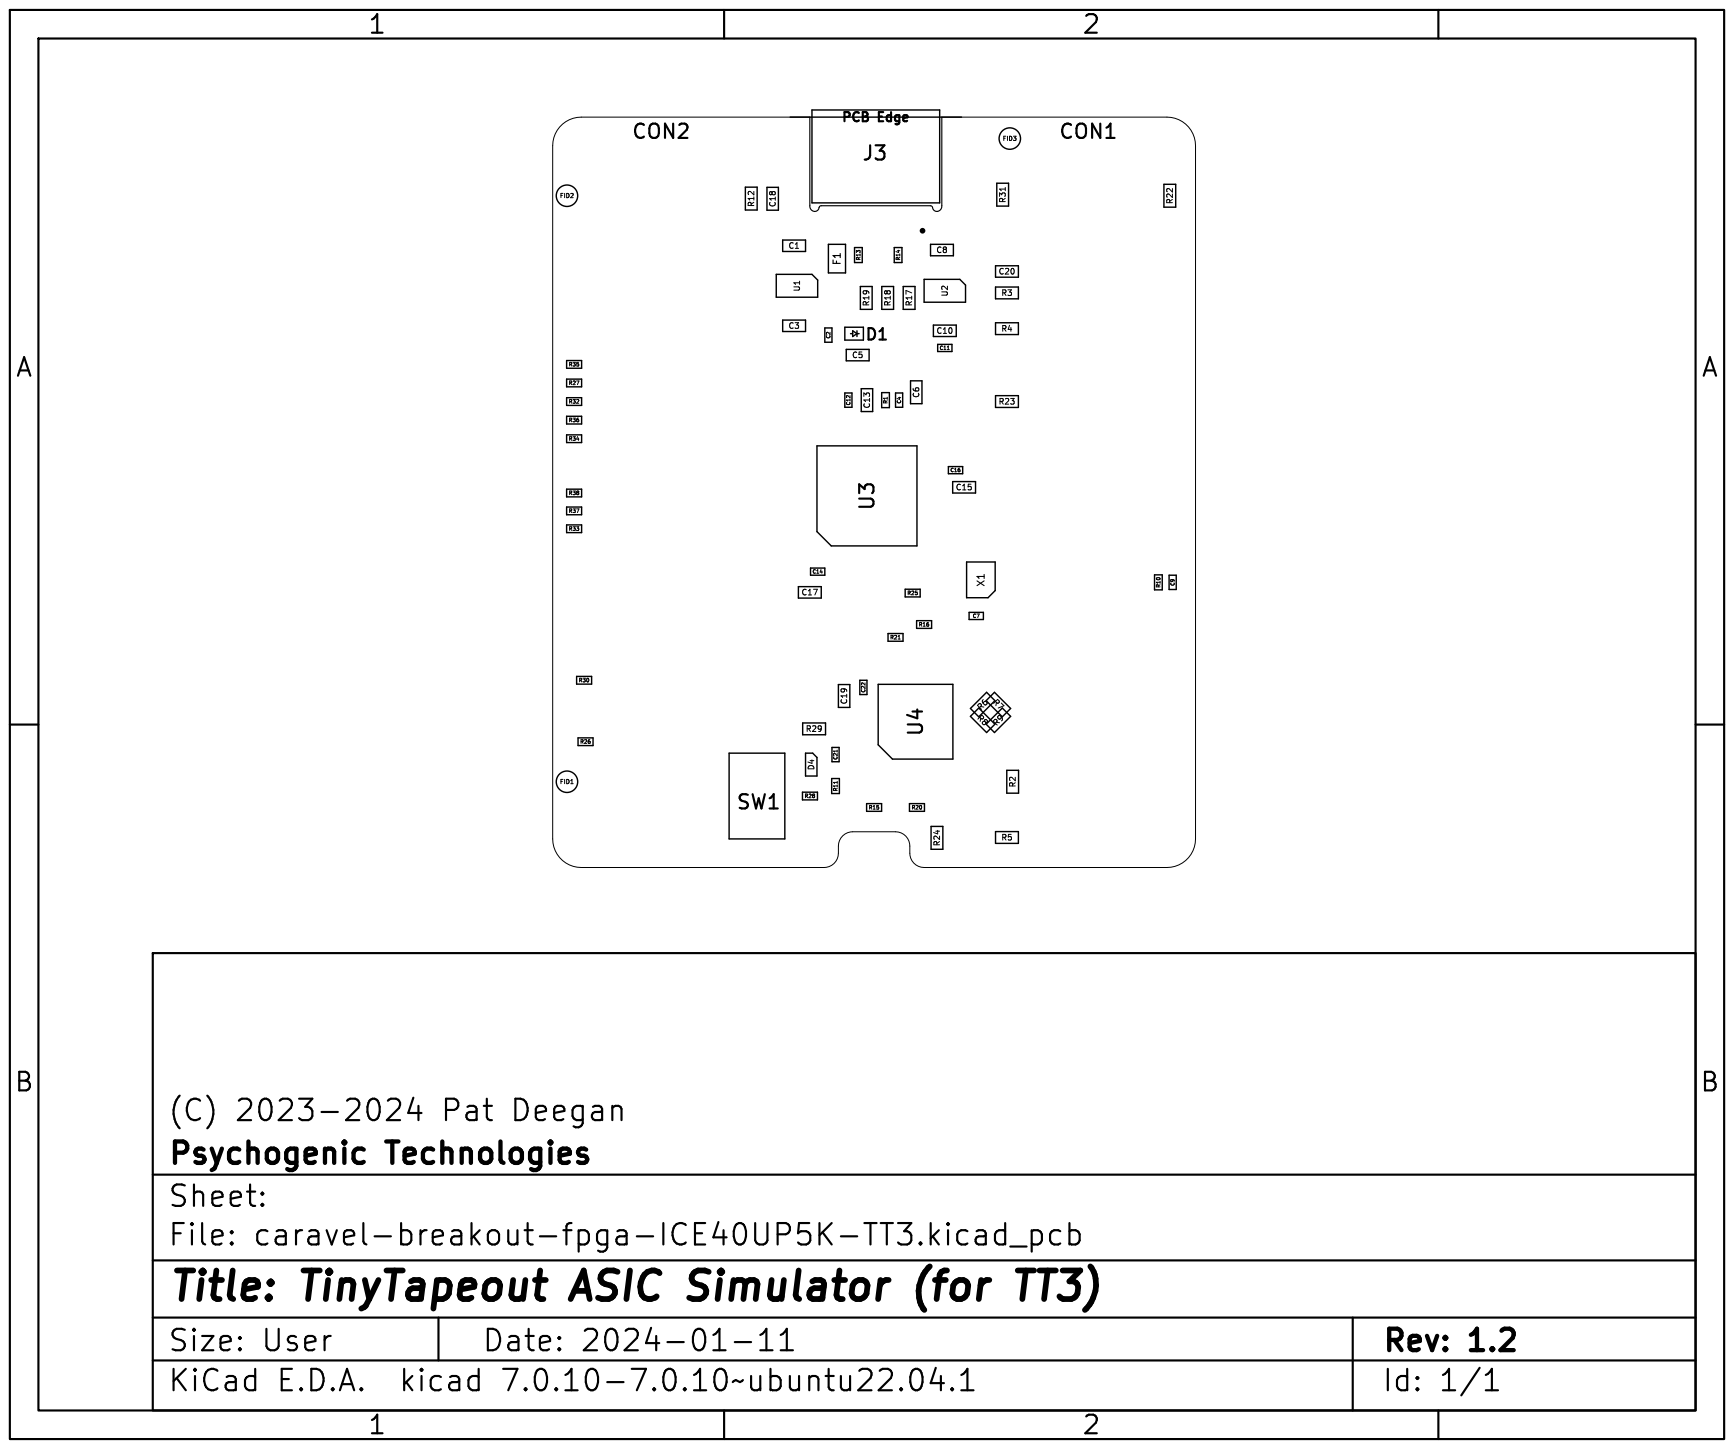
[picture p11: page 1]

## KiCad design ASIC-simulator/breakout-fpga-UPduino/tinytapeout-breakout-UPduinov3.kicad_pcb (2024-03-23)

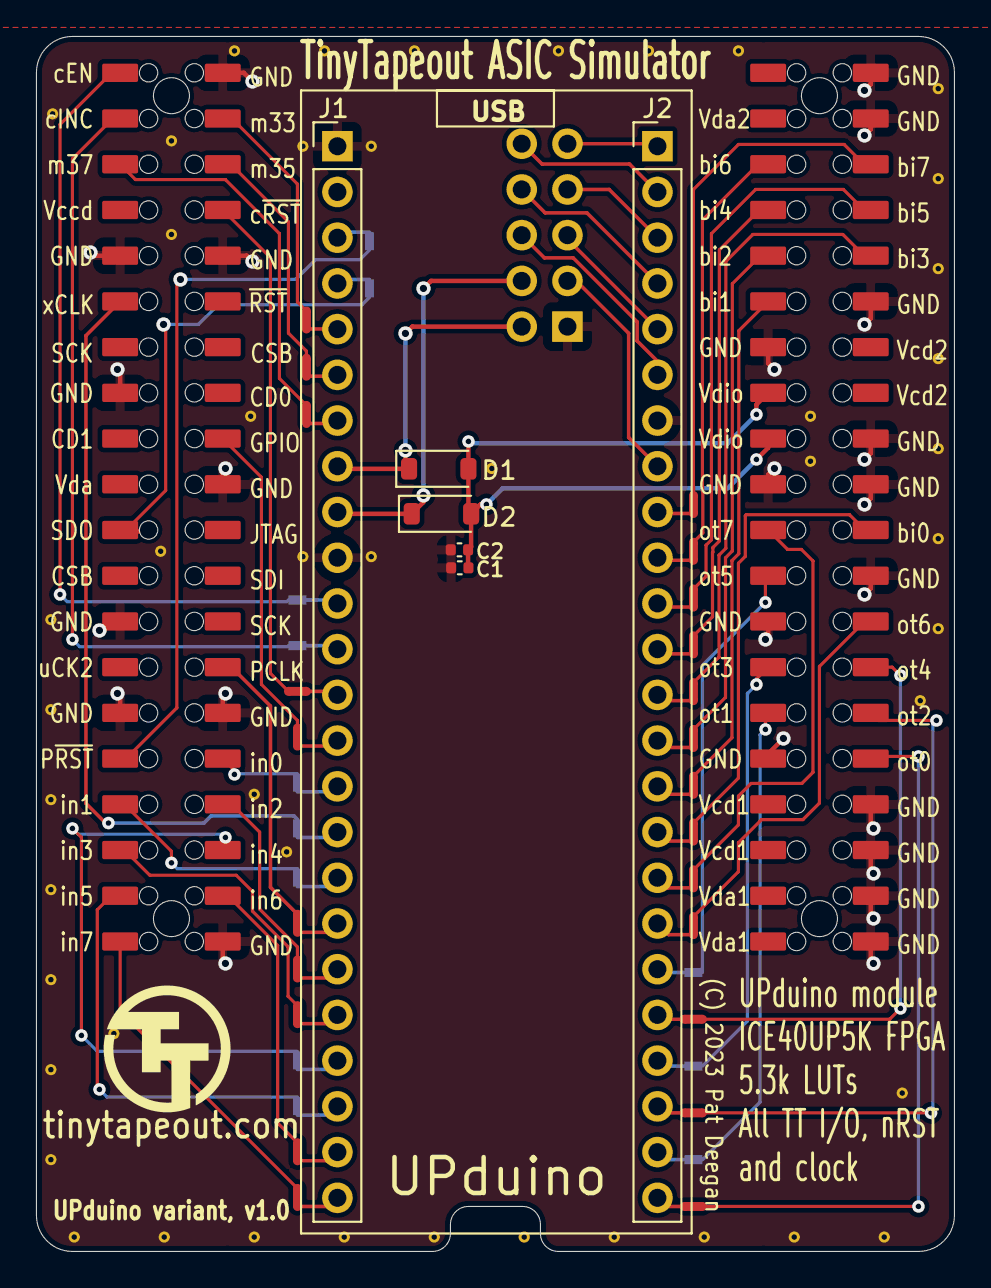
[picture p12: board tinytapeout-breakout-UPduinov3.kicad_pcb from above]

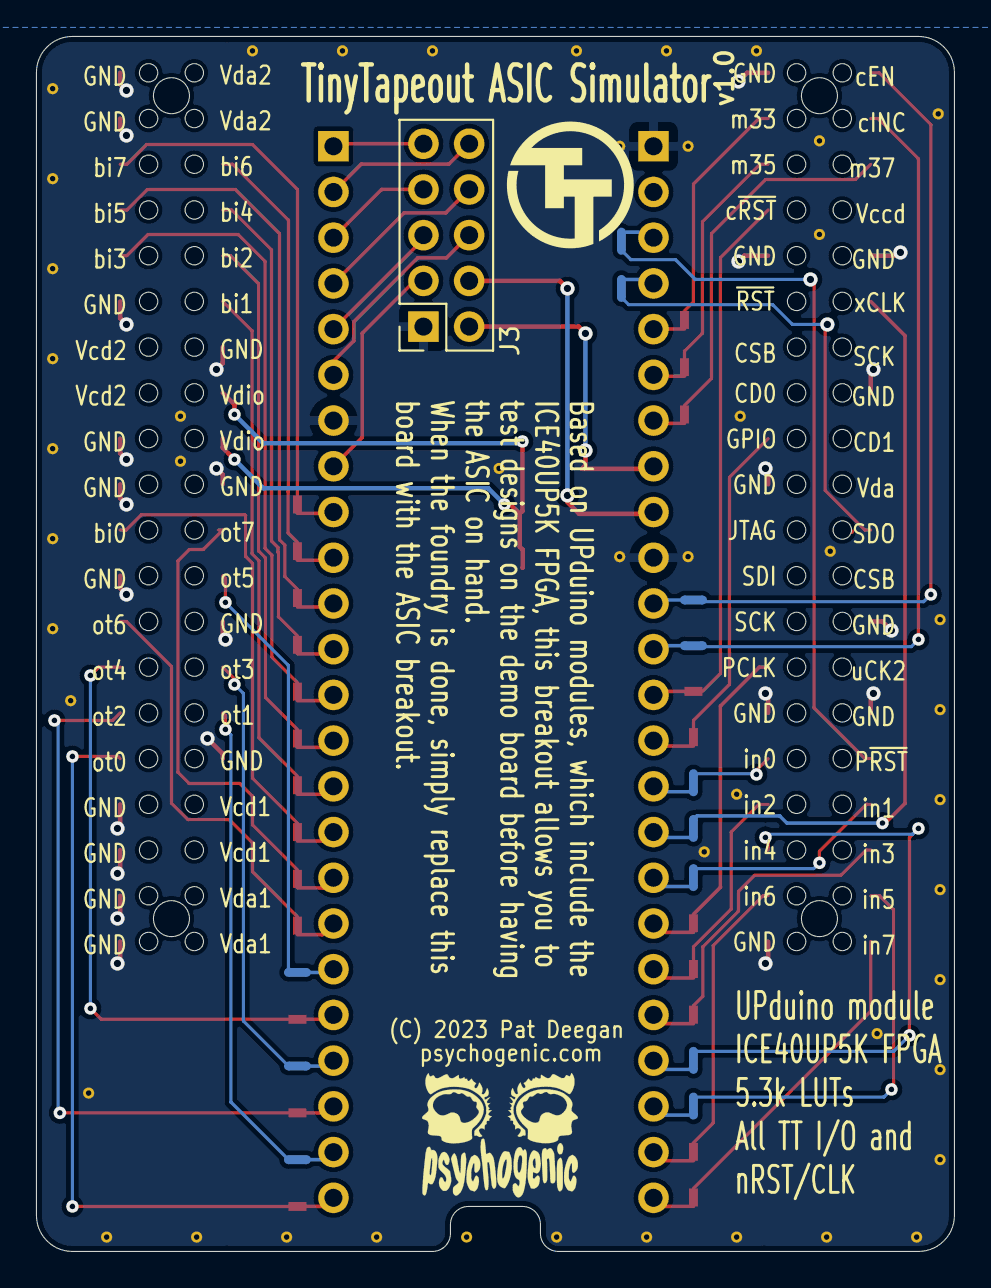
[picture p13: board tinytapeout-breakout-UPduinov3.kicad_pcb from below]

Board: 2 copper layers, 51.0 x 67.5 mm, 91 parts (13 on the bottom side), 85 nets.

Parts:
C1, C2: 0.1uf; C_0402_1005Metric
CON1, CON2: REF-182665-01; FH-00339
D1, D2: B0520LW-7-F; D_SOD-123
J1: UPduinoA; PinHeader_1x24_P2.54mm_Vertical
J2: UPduinoB; PinHeader_1x24_P2.54mm_Vertical
J3: Conn_02x05_Odd_Even; PinSocket_2x05_P2.54mm_Vertical
NT1, NT2, NT3, NT4, NT5, NT6, NT7, NT8, NT9, NT10, NT11, NT12, NT13, NT14, NT15, NT16, NT17, NT18, NT19, NT20, NT21, NT22, NT23, NT24, NT25, NT26, NT27, NT28, NT29, NT30, NT31, NT32, NT33, NT34, NT35: NetTie_2; NetTie-2_SMD_Pad0.5mm
STITCH1, STITCH2, STITCH3, STITCH4, STITCH5, STITCH6, STITCH7, STITCH8, STITCH9, STITCH10, STITCH10#2, STITCH10#3, STITCH11, STITCH12, STITCH13, STITCH14, STITCH15, STITCH16, STITCH17, STITCH18, STITCH19, STITCH20, STITCH21, STITCH22, STITCH22#2, STITCH22#3, STITCH22#4, STITCH22#5, STITCH22#6, STITCH22#7, STITCH22#8, STITCH22#9, STITCH22#10, STITCH22#11, STITCH22#12, STITCH22#13, STITCH22#14, STITCH23, STITCH24, STITCH25, STITCH26, STITCH27, STITCH28, STITCH28#2, STITCH28#3, STITCH28#4, STITCH28#5: StitchingVia-0.3mm

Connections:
/3v3UP: D2.1 (K), J1.9, J3.4
/5VUSB: D1.1 (K), J1.8, J3.2
/CDONE: J1.4, NT2.2
/CLK_12M_EXT: J2.8, J3.3
/CRESET_N: J1.3, NT1.2
/FLASH_MISO: J2.4, J3.8
/FLASH_MOSI: J2.3, J3.7
/FT_SCK: J2.2, J3.10
/FT_SSn: J2.1, J3.9
/IOB_0A: J2.23, NT34.2
/IOB_2A: J2.22, NT33.2
/IOB_3B_G6: J2.17, NT28.2
/IOB_4A: J2.20, NT31.2
/IOB_5B: J2.21, NT32.2
/IOB_6A: J2.24, NT35.2
/IOB_8A: J2.18, NT29.2
/IOB_9B: J2.19, NT30.2
/IOB_13B: J2.16, NT27.2
/IOB_16A: J2.15, NT26.2
/IOB_18A: J2.6, J3.6
/IOB_20A: J2.14, NT25.2
/IOB_22A: J2.9, NT20.2
/IOB_23B: J2.10, NT21.2
/IOB_24A: J2.11, NT22.2
/IOB_25B_G3: J2.5, J3.5
/IOB_29B: J2.12, NT23.2
/IOB_31B: J2.13, NT24.2
/IOT_36B: J1.12, NT7.2
/IOT_37A: J1.11, NT6.2
/IOT_38B: J1.14, NT9.2
/IOT_39A: J1.13, NT8.2
/IOT_41A: J1.24, NT19.2
/IOT_42B: J1.17, NT12.2
/IOT_43A: J1.15, NT10.2
/IOT_44B: J1.19, NT14.2
/IOT_45A_G1: J1.18, NT13.2
/IOT_46B_G0: J1.16, NT11.2
/IOT_48B: J1.21, NT16.2
/IOT_49A: J1.20, NT15.2
/IOT_50B: J1.23, NT18.2
/IOT_51A: J1.22, NT17.2
/LED_B: J1.7, NT5.2
/LED_G: J1.6, NT4.2
/LED_R: J1.5, NT3.2
GND: C1.1, C2.1, CON1.2, CON1.9, CON1.10, CON1.15, CON1.20, CON1.25, CON1.29, CON1.30, CON1.40, CON2.2, CON2.4, CON2.12, CON2.13, CON2.18, CON2.19, CON2.20, CON2.24, CON2.25, CON2.31, CON2.34, CON2.36, CON2.38, CON2.40, J1.1, J1.10, J2.7, J3.1, STITCH1.1, STITCH2.1, STITCH3.1, STITCH4.1, STITCH5.1, STITCH6.1, STITCH7.1, STITCH8.1, STITCH9.1, STITCH10.1, STITCH10#2.1, STITCH10#3.1, STITCH11.1, STITCH12.1, STITCH13.1, STITCH14.1, STITCH15.1, STITCH16.1, STITCH17.1, STITCH18.1, STITCH19.1, STITCH20.1, STITCH21.1, STITCH22.1, STITCH22#2.1, STITCH22#3.1, STITCH22#4.1, STITCH22#5.1, STITCH22#6.1, STITCH22#7.1, STITCH22#8.1, STITCH22#9.1, STITCH22#10.1, STITCH22#11.1, STITCH22#12.1, STITCH22#13.1, STITCH22#14.1, STITCH23.1, STITCH24.1, STITCH25.1, STITCH26.1, STITCH27.1, STITCH28.1, STITCH28#2.1, STITCH28#3.1, STITCH28#4.1, STITCH28#5.1
SDO/mio[1]: CON1.21, NT2.1
clk/mio[6]: CON1.28, NT13.1
ctrl_ena/mio[32]: CON1.1, NT6.1
ctrl_sel_inc/mio[34]: CON1.3, NT7.1
gpio: CON1.18, NT9.1
mio[33]: CON1.4, NT3.1
mio[35]: CON1.6, NT4.1
mio[37]: CON1.5, NT5.1
ui_in[0]/mio[8]: CON1.32, NT10.1
ui_in[1]/mio[9]: CON1.33, NT12.1
ui_in[2]/mio[10]: CON1.34, NT14.1
ui_in[3]/mio[11]: CON1.35, NT15.1
ui_in[4]/mio[12]: CON1.36, NT16.1
ui_in[5]/mio[13]: CON1.37, NT17.1
ui_in[6]/mio[14]: CON1.38, NT18.1
ui_in[7]/mio[15]: CON1.39, NT19.1
uio[0]/mio[24]: CON2.22, NT27.1
uio[1]/mio[25]: CON2.11, NT26.1
uio[2]/mio[26]: CON2.9, NT25.1
uio[3]/mio[27]: CON2.10, NT24.1
uio[4]/mio[28]: CON2.7, NT23.1
uio[5]/mio[29]: CON2.8, NT22.1
uio[6]/mio[30]: CON2.5, NT21.1
uio[7]/mio[31]: CON2.6, NT20.1
uo_out[0]/mio[16]: CON2.32, NT35.1
uo_out[1]/mio[17]: CON2.29, NT34.1
uo_out[2]/mio[18]: CON2.30, NT33.1
uo_out[3]/mio[19]: CON2.27, NT32.1
uo_out[4]/mio[20]: CON2.28, NT31.1
uo_out[5]/mio[21]: CON2.23, NT30.1
uo_out[6]/mio[22]: CON2.26, NT29.1
uo_out[7]/mio[23]: CON2.21, NT28.1
vccd1: CON2.33, CON2.35
vccd2: CON2.14, CON2.16
vdda1: CON2.37, CON2.39
vdda2: CON2.1, CON2.3
vddio: C1.2, C2.2, CON2.15, CON2.17, D1.2 (A), D2.2 (A)
xclk: CON1.11, NT11.1
~ctrl_sel_rst/mio[36]: CON1.8, NT8.1
~rst/mio[7]: CON1.31, NT1.1

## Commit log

2022-12-21 rename boards/re-org repo
    [caravel-breakout-wlcsp-RevA1.kicad_pcb, caravel-breakout-wlcsp-RevA1.kicad_sch]
2022-12-24 remove libs
    moved to https://github.com/omerk/ok-kicad-libs
2022-12-24 WIP checkin for comments
    [caravel-breakout-bitsy-RevA1.kicad_pcb, caravel-breakout-bitsy-RevA1.kicad_sch, caravel-breakout-qfn-RevA1.kicad_pcb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]
2023-02-05 initial check-in for RevA1
    [caravel-breakout-wlcsp-RevA1.kicad_pcb, caravel-breakout-wlcsp-RevA1.kicad_sch]
2023-06-20 Update to logos, resource refactor, kicad 7 migration
    [caravel-breakout-wlcsp-RevA1.kicad_pcb, caravel-breakout-wlcsp-RevA1.kicad_sch]
2023-06-20 Revision A2 release and re-org
    [caravel-breakout-wlcsp.kicad_pcb, caravel-breakout-wlcsp.kicad_sch]
2023-06-20 Added fids and patch over-reliance on gnd fill for conn DRC fails
    [caravel-breakout-wlcsp.kicad_pcb, caravel-breakout-wlcsp.kicad_sch]
2023-07-17 kicad 7 migration, qfn symbol and wiring
    [caravel-breakout-qfn-RevA1.kicad_pcb, caravel-breakout-qfn-RevA1.kicad_sch]
2023-07-17 use git for versionning
    [caravel-breakout-qfn.kicad_pcb, caravel-breakout-qfn.kicad_sch]
2023-07-17 RevA1 removed from paths
    [caravel-breakout-qfn.kicad_pcb, caravel-breakout-qfn.kicad_sch]
2023-07-17 pre-route, DRC setup, floorplan for 2-layer top
    [caravel-breakout-qfn.kicad_pcb]
2023-07-17 routing prelim complete
    [caravel-breakout-qfn.kicad_pcb]
2023-07-17 sheet and origin cleanup
    [caravel-breakout-qfn.kicad_pcb]
2023-07-21 QFN breakout v2.1: fixes to footprint s.masks, cleanup, flipped logos
    [caravel-breakout-qfn.kicad_pcb, caravel-breakout-qfn.kicad_sch]
2023-07-26 footprint for cheaper chinese header
2023-07-26 aisler requested mods
    [caravel-breakout-wlcsp.kicad_pcb]
2023-07-26 QFN v2.2, using cheaper FH-00339 headers
    [caravel-breakout-qfn.kicad_pcb, caravel-breakout-qfn.kicad_sch]
2024-03-23 QFN breakout sanity naming for nets
    [caravel-breakout-qfn.kicad_pcb, caravel-breakout-qfn.kicad_sch]
2024-03-23 v3.0, breaking changes for ultra-goodness: EMC,TT pinout, FPGA
    [caravel-breakout-qfn.kicad_pcb, caravel-breakout-qfn.kicad_sch]
2024-03-23 Comments and cleanup
    [caravel-breakout-qfn.kicad_pcb, caravel-breakout-qfn.kicad_sch]
2024-03-23 aisler bridge markers
    [caravel-breakout-qfn.kicad_pcb]
2024-03-23 Added deglitch/delay on Caravel nRST
    [caravel-breakout-qfn.kicad_pcb, caravel-breakout-qfn.kicad_sch]
2024-03-23 Silkscreen cleanup
    [caravel-breakout-qfn.kicad_pcb]
2024-03-23 Initial ASIC FPGA simulator breakouts import
    [caravel-breakout-fpga-TinyFPGABX-TT3.kicad_pcb, caravel-breakout-fpga-TinyFPGABX-TT3.kicad_sch, tinytapeout-breakout-TinyFPGABX.kicad_pcb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]
2024-03-23 FPGA breakout, TT3 ICE40UP5K, initial commit
    [caravel-breakout-fpga-ICE40UP5K-TT3-B_Cu.gbr, caravel-breakout-fpga-ICE40UP5K-TT3-B_Mask.gbr, caravel-breakout-fpga-ICE40UP5K-TT3-B_Paste.gbr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]
2024-03-23 ICE40UP5K TT3 breakout, BOM tweaks pre-PCBA first run
    [caravel-breakout-fpga-ICE40UP5K-TT3.kicad_pcb, caravel-breakout-fpga-ICE40UP5K-TT3.kicad_sch]
2024-03-23 PCBA mods, new boot selector switch
    [caravel-breakout-fpga-ICE40UP5K-TT3.kicad_pcb, caravel-breakout-fpga-ICE40UP5K-TT3.kicad_sch]
2024-03-23 v1.2 ready for pcba
    [caravel-breakout-fpga-ICE40UP5K-TT3.kicad_pcb, caravel-breakout-fpga-ICE40UP5K-TT3.kicad_sch]
2024-03-23 PCBA BOM and placement CSVs
    [BOM.csv, caravel-breakout-fpga-ICE40UP5K-TT3-all.csv, caravel-breakout-fpga-ICE40UP5K-TT3-demodependent.csv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]
2024-03-23 gerber reorg
    [caravel-breakout-fpga-ICE40UP5K-TT3-B_Cu.gbr, caravel-breakout-fpga-ICE40UP5K-TT3-B_Mask.gbr, caravel-breakout-fpga-ICE40UP5K-TT3-B_Paste.gbr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]
2024-03-23 TT03p5, as fabbed
    [caravel-breakout-qfn.kicad_pcb, caravel-breakout-qfn.kicad_sch]
2024-03-23 v3.2 moved to bottom side pin headers
    [caravel-breakout-qfn.kicad_pcb, caravel-breakout-qfn.kicad_sch]

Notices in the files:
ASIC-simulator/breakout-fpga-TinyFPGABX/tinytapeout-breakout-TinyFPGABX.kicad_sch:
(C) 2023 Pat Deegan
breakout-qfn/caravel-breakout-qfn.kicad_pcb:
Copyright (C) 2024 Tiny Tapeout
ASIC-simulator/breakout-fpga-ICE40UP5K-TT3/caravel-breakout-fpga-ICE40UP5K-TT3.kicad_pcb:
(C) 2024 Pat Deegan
